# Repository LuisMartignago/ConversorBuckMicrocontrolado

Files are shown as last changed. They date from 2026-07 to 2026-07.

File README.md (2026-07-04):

# Conversor Buck Microcontrolado

Projeto de um conversor CC-CC abaixador (Buck Converter) com controle digital implementado em um microcontrolador **CH32V003**, desenvolvido com foco em aplicações de eletrônica de potência, sistemas embarcados e controle digital.

O projeto contempla o desenvolvimento completo do hardware e do firmware, incluindo o dimensionamento da etapa de potência, condicionamento dos sinais analógicos, controle por PWM, algoritmo de controle PI, proteção contra sobrecorrente e interface de comunicação serial.

---

## Principais características

* Conversor Buck microcontrolado.
* Controle digital de tensão utilizando controlador **PI**.
* Geração de PWM por hardware utilizando o temporizador **TIM1**.
* Aquisição de tensão e corrente através do ADC.
* Conversão automática utilizando **ADC + DMA**.
* Comunicação serial UART para monitoramento e configuração.
* Limitação de corrente por software.
* Controle de rampa (*Rate Limiter*) para partida suave e alterações da referência.
* Proteção contra *Integral Windup*.
* Firmware desenvolvido em linguagem C.
* Hardware desenvolvido no KiCad.

---

## Hardware

O conversor é composto pelos seguintes blocos principais:

* Microcontrolador **CH32V003**;
* Conversor Buck de potência;
* Driver para acionamento do MOSFET;
* Fonte auxiliar isolada para alimentação do gate driver;
* Reguladores de tensão para alimentação dos circuitos de controle;
* Divisor resistivo para medição da tensão;
* Resistor shunt para medição da corrente;
* Amplificador operacional interno do CH32V003 para condicionamento do sinal de corrente.

---

## Estratégia de controle

O controle da tensão de saída é realizado por um controlador **Proporcional–Integral (PI)**.

A implementação inclui:

* cálculo periódico do erro;
* atualização do termo integral;
* limitação do integrador (*Anti-Windup*);
* saturação da saída do controlador;
* atualização do ciclo de trabalho do PWM.

Para reduzir transitórios durante alterações da referência, foi implementado um algoritmo de **Rate Limiter**, permitindo variações graduais da tensão de saída.

Como mecanismo adicional de proteção, quando a corrente ultrapassa o limite configurado, a referência de tensão é reduzida gradualmente e o integrador do controlador é parcialmente descarregado, proporcionando recuperação rápida após a remoção da condição de sobrecorrente.

---

## Comunicação Serial

O firmware disponibiliza uma interface UART para:

* monitoramento da tensão;
* monitoramento da corrente;
* ajuste de parâmetros;
* depuração do sistema.

A transmissão utiliza **DMA**, reduzindo significativamente a utilização da CPU.

---

## Estrutura do repositório

```text
.
├── Firmware/
├── Hardware/
│   ├── Esquemáticos
│   ├── PCB
│   └── Bibliotecas
├── Documentação/
├── Imagens/
└── README.md
```

---

## Ferramentas utilizadas

* KiCad
* GCC para RISC-V
* WCH MounRiver Studio
* Git
* GitHub

---

## Aplicações

Este projeto pode ser utilizado como base para:

* estudos de Eletrônica de Potência;
* Sistemas Embarcados;
* Controle Digital;
* Fontes chaveadas;
* Conversores CC-CC;
* projetos acadêmicos;
* trabalhos de conclusão de curso.

---

## Licença

Este projeto está disponibilizado para fins acadêmicos e de pesquisa.

---

Caso este projeto seja utilizado em trabalhos acadêmicos, solicita-se a devida citação do repositório.

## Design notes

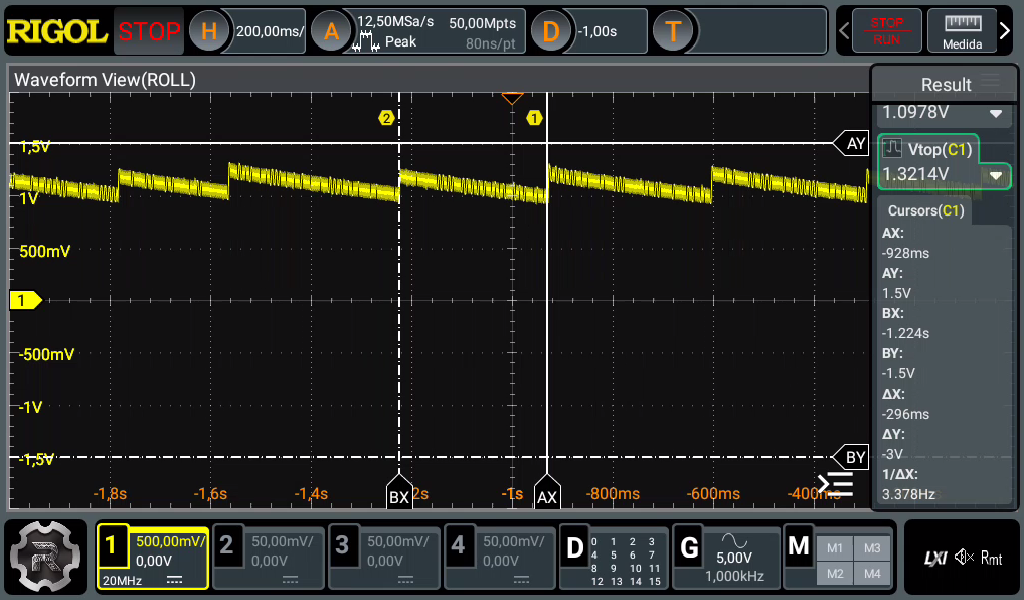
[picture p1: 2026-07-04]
FotosSaida/DMAuart.png

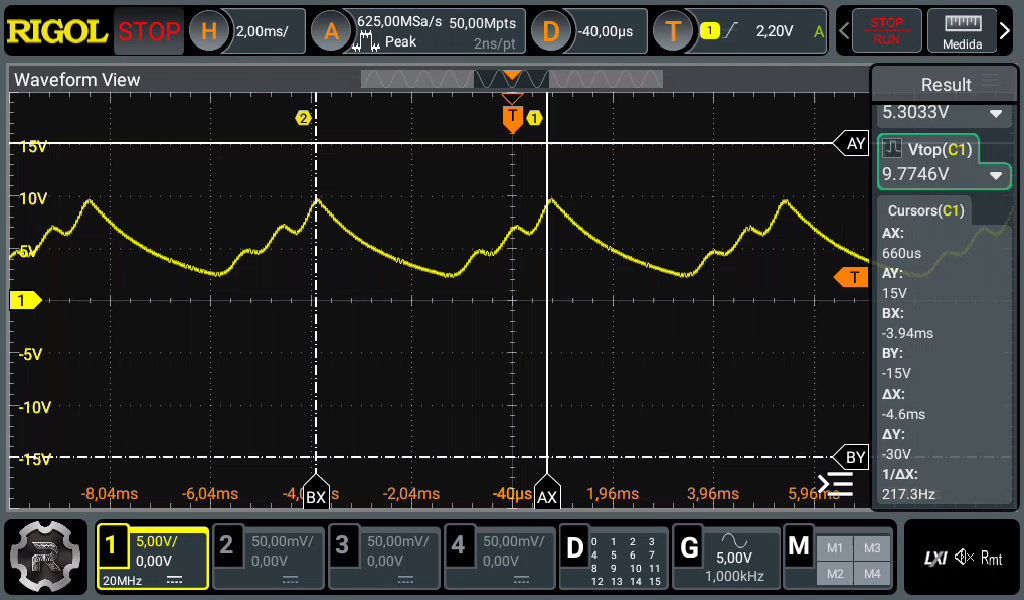
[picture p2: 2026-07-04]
FotosSaida/LimiteCorente.png

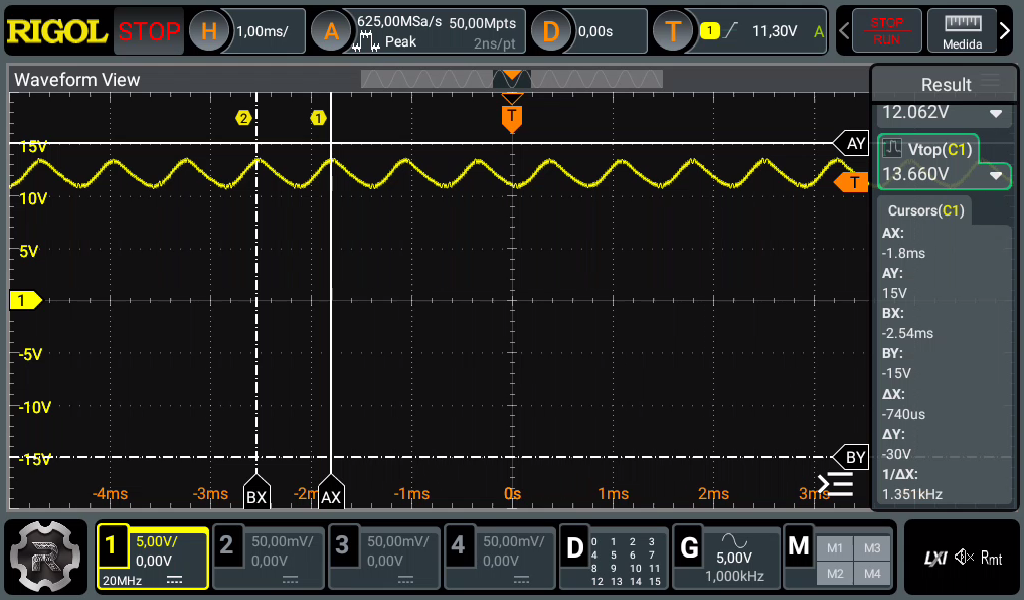
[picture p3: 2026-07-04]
FotosSaida/ProblemaSprintf.png

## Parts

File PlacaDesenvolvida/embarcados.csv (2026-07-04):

Id | Designador | Footprint | Quantidade | Designação | Fornecedor e referência
1 | C1, C2, C3 | CP_Elec_10x10 | 3 | 220uF
2 | C4, C5, C6 | C_1210_3225Metric_Pad1.33x2.70mm_HandSolder | 3 | 10uF
3 | C7, C8, C9, C10, C12, C13, C16, C18 | C_0603_1608Metric_Pad1.08x0.95mm_HandSolder | 8 | 0u1
4 | C11, C14, C15 | CP_Elec_4x3.9 | 3 | 10u
5 | C17 | C_0603_1608Metric_Pad1.08x0.95mm_HandSolder | 1 | 12p
6 | D1 | D_A-405_P7.62mm_Horizontal | 1 | D_Zener
7 | D2 | D_A-405_P7.62mm_Horizontal | 1 | ZMM15V
8 | D3, D4 | D_A-405_P7.62mm_Horizontal | 2 | 1N4148
9 | J1, J2 | TerminalBlock_MaiXu_MX126-5.0-02P_1x02_P5.00mm | 2 | Screw_Terminal_01x02
10 | J3 | PinHeader_1x03_P2.54mm_Vertical | 1 | Conn_01x03_Pin
11 | J4 | PinHeader_1x02_P2.54mm_Vertical | 1 | Conn_01x03_Pin
12 | L1 | IndutorEmbarcados | 1 | 470u
13 | PS1 | B1212s | 1 | B1212S
14 | Q1 | TDSON-8-1 | 1 | BSC190N15NS3G(TOKMAS)
15 | Q2 | SOT-323_SC-70 | 1 | PNP
16 | Q3 | TO-126-3_Vertical | 1 | BD139
17 | R2 | R_0603_1608Metric_Pad0.98x0.95mm_HandSolder | 1 | 10kΩ
18 | R4, R5 | R_1210_3225Metric_Pad1.30x2.65mm_HandSolder | 2 | 10Ω
19 | R6 | R_1210_3225Metric_Pad1.30x2.65mm_HandSolder | 1 | 220R
20 | R7 | R_0603_1608Metric_Pad0.98x0.95mm_HandSolder | 1 | 4k7
21 | R8, R9 | R_1210_3225Metric_Pad1.30x2.65mm_HandSolder | 2 | 0R1
22 | R10, R13 | R_Axial_DIN0207_L6.3mm_D2.5mm_P7.62mm_Horizontal | 2 | 10k
23 | R11, R12 | R_Axial_DIN0207_L6.3mm_D2.5mm_P7.62mm_Horizontal | 2 | 20k
24 | R14 | R_0603_1608Metric_Pad0.98x0.95mm_HandSolder | 1 | 15k
25 | R15 | R_0603_1608Metric_Pad0.98x0.95mm_HandSolder | 1 | 330R
26 | TP1 | TestPoint_Bridge_Pitch2.54mm_Drill0.7mm | 1 | GATE
27 | TP2 | TestPoint_Bridge_Pitch2.54mm_Drill0.7mm | 1 | SOURCE
28 | TP3 | TestPoint_Bridge_Pitch2.54mm_Drill0.7mm | 1 | I_amp
29 | TP4 | TestPoint_Bridge_Pitch2.54mm_Drill0.7mm | 1 | VOUT
30 | U1 | TO-263-2 | 1 | MUR1620CT
31 | U2 | SSO-6_6.8x4.6mm_P1.27mm_Clearance8mm | 1 | FOD8342TR2
32 | U3 | TO-220-3_Vertical | 1 | LM7812_TO220
33 | U4 | TO-263-3_TabPin2 | 1 | LM1084-5.0
34 | U5 | TSSOP-20_4.4x6.5mm_P0.65mm | 1 | CH32V003FxPx

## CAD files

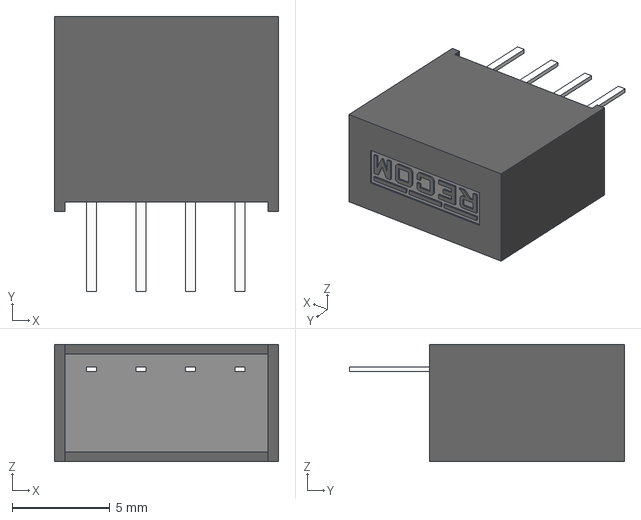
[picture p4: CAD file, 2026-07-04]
PlacaDesenvolvida/RO-1212S-HP--3DModel-STEP-1.STEP
11.5 x 14.1 x 6.00 mm

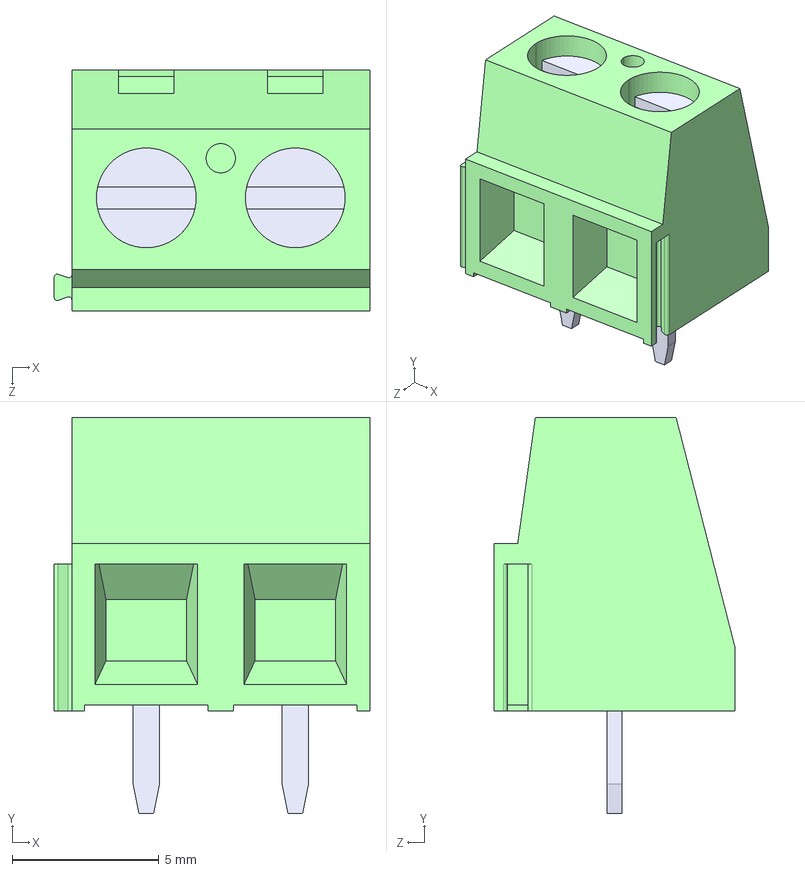
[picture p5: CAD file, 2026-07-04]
PlacaDesenvolvida/282837-2--3DModel-STEP-269445.STEP
10.8 x 13.5 x 8.20 mm

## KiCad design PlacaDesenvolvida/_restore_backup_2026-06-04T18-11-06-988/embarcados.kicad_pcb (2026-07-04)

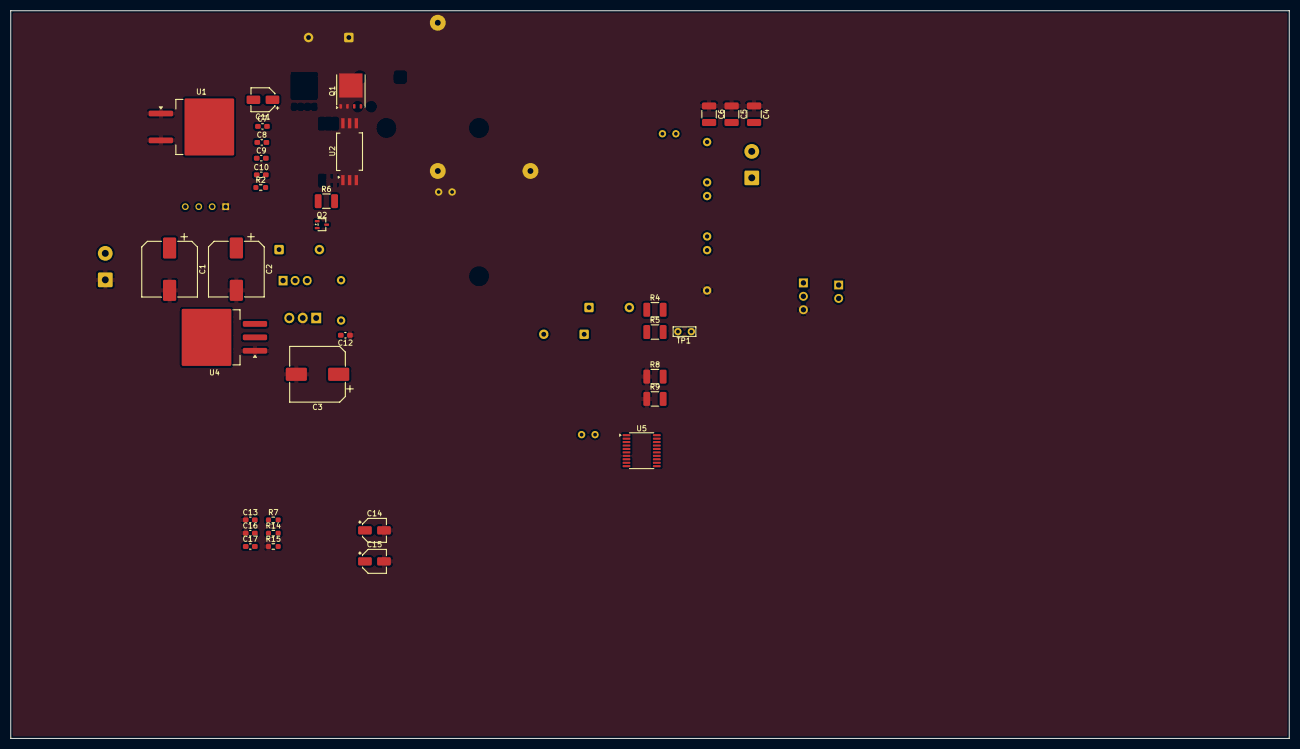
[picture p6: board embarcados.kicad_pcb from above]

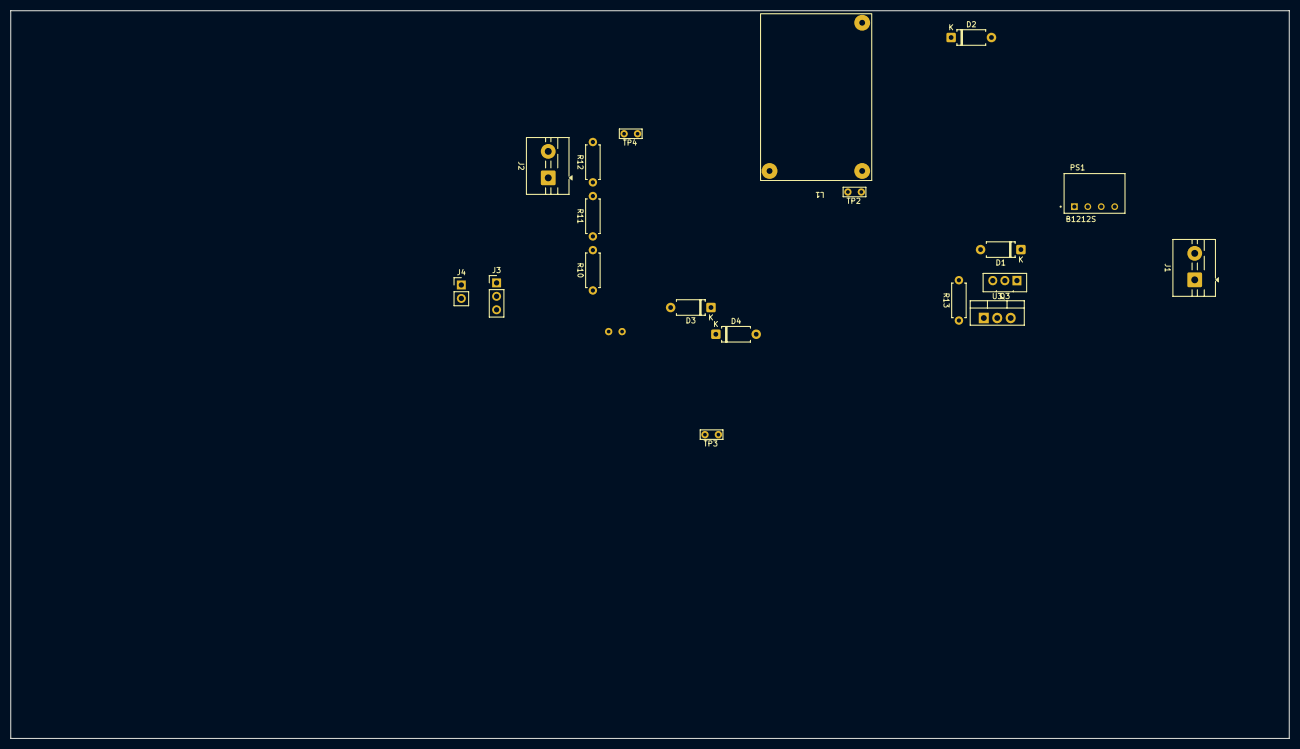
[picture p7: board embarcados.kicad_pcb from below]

Board: 2 copper layers, 241.5 x 137.5 mm, 52 parts (19 on the bottom side), 24 nets, no tracks yet.

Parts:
C1, C2, C3: 220uF; CP_Elec_10x10
C4, C5, C6: 10uF; C_1210_3225Metric_Pad1.33x2.70mm_HandSolder
C7, C8, C9, C10, C12, C13, C16: 0u1; C_0603_1608Metric_Pad1.08x0.95mm_HandSolder
C11, C14, C15: 10u; CP_Elec_4x3.9
C17: 12p; C_0603_1608Metric_Pad1.08x0.95mm_HandSolder
D1: D_Zener; D_A-405_P7.62mm_Horizontal
D2: ZMM15V; D_A-405_P7.62mm_Horizontal
D3, D4: 1N4148; D_A-405_P7.62mm_Horizontal
J1, J2: Screw_Terminal_01x02; TerminalBlock_MaiXu_MX126-5.0-02P_1x02_P5.00mm
J3: Conn_01x03_Pin; PinHeader_1x03_P2.54mm_Vertical
J4: Conn_01x03_Pin; PinHeader_1x02_P2.54mm_Vertical
L1: 470u; IndutorEmbarcados
PS1: B1212S; B1212s
Q1: BSC190N15NS3G(TOKMAS); TDSON-8-1
Q2: PNP; SOT-323_SC-70
Q3: BD139; TO-126-3_Vertical
R2: 10kΩ; R_0603_1608Metric_Pad0.98x0.95mm_HandSolder
R4, R5: 10Ω; R_1210_3225Metric_Pad1.30x2.65mm_HandSolder
R6: 220R; R_1210_3225Metric_Pad1.30x2.65mm_HandSolder
R7: 4k7; R_0603_1608Metric_Pad0.98x0.95mm_HandSolder
R8, R9: 0R1; R_1210_3225Metric_Pad1.30x2.65mm_HandSolder
R10, R13: 10k; R_Axial_DIN0207_L6.3mm_D2.5mm_P7.62mm_Horizontal
R11, R12: 20k; R_Axial_DIN0207_L6.3mm_D2.5mm_P7.62mm_Horizontal
R14: 15k; R_0603_1608Metric_Pad0.98x0.95mm_HandSolder
R15: 330R; R_0603_1608Metric_Pad0.98x0.95mm_HandSolder
TP1: GATE; TestPoint_Bridge_Pitch2.54mm_Drill0.7mm
TP2: SOURCE; TestPoint_Bridge_Pitch2.54mm_Drill0.7mm
TP3: I_amp; TestPoint_Bridge_Pitch2.54mm_Drill0.7mm
TP4: VOUT; TestPoint_Bridge_Pitch2.54mm_Drill0.7mm
U1: MUR1620CT; TO-263-2
U2: FOD8342TR2; SSO-6_6.8x4.6mm_P1.27mm_Clearance8mm
U3: LM7812_TO220; TO-220-3_Vertical
U4: LM1084-5.0; TO-263-3_TabPin2
U5: CH32V003FxPx; TSSOP-20_4.4x6.5mm_P0.65mm

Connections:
+5V: C15.1, C16.2, J3.1, Q2.3 (E), U4.2 (VO), U5.9 (VDD)
+12V: C13.2, C14.1, PS1.2 (+VIN), U3.3 (VO), U4.3 (VI)
+12Visolated: C7.2, C8.2, C9.2, C10.2, C11.1, PS1.4 (+VOUT), U2.6 (VDD)
+24V: C1.1, C2.1, D1.1 (K), J1.2, Q1.5 (D), Q3.2 (C)
GND: C1.2, C2.2, C3.2, C4.1, C5.1, C6.1, C12.1, C13.1, C14.2, C15.2, C16.1, J1.1, J3.3, PS1.1 (-VIN), R8.1, R9.1, R10.1, R15.1, U1.1 (A), U1.3 (A), U2.2 (NC), U2.3 (CATHODE), U3.2 (GND), U4.1 (GND), U5.7 (VSS)
I_sense: J2.1, R8.2, R9.2, U5.4 (PD7)
unnamed: D1.2 (A), Q3.3 (B), R13.2
unnamed: D2.1 (K), Q1.4 (G), R2.2, R4.2, R5.2, TP1.1 (1_1)
unnamed: D3.2 (A), D4.1 (C), U2.5 (VO)
unnamed: D3.1 (C), R4.1
unnamed: D4.2 (A), R5.1
unnamed: Q2.2 (B), R7.2
unnamed: Q2.1 (C), R6.1
unnamed: C3.1, C12.2, Q3.1 (E), R13.1, U3.1 (VI)
unnamed: R11.2, R12.1
unnamed: R6.2, U2.1 (ANODE)
unnamed: C17.2, R14.2, R15.2, U5.8 (PD0)
unnamed: C17.1, R14.1, TP3.1 (1_1), U5.1 (PD4)
PD1: J3.2, U5.18 (PD1)
RX: J4.2, U5.3 (PD6)
TX: J4.1, U5.2 (PD5)
VSS: C7.1, C8.1, C9.1, C10.1, C11.2, D2.2 (A), L1.1, PS1.3 (-VOUT), Q1.1 (S), Q1.2 (S), Q1.3 (S), R2.1, TP2.1 (1_1), U1.2 (C), U2.4 (VSS)
Vout+: C4.2, C5.2, C6.2, J2.2, L1.2, R12.2, TP4.1 (1_1)
Vsense: R10.2, R11.1, U5.19 (PD2)

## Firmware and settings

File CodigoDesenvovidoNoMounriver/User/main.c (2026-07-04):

#include "debug.h"


// ======== Variaveis Globais ======== //

// -------- ADC --------
#define V_pin GPIO_Pin_2
#define I_pin GPIO_Pin_4
#define V_ADC ADC_Channel_3
#define I_ADC ADC_Channel_7

#define V_sample ADC_SampleTime_30Cycles
#define I_sample ADC_SampleTime_30Cycles
volatile u16 adc_buf[2];
volatile u16 ADC_COMPLETE;
volatile u16 V_lido;
volatile u16 I_lido;

// -------- USART --------
volatile uint32_t V_recebido = 0;
volatile uint32_t I_recebido = 0;
#define TxSize (size (exemplo_TX))
#define RxSize (size (exemplo_RX))
#define size(a) (sizeof (a) / sizeof (*(a)))
#define exemplo_TX "V:1023,I:1023\r\n"
#define exemplo_RX "V:1023,I:1023\r\n"

volatile char TxBuffer[TxSize] = {0};
volatile char RxBuffer[RxSize] = {0};
volatile u32 Tx_pronto = 0;
volatile u32 Rx_pronto = 0;

//--------- Variaveis Globais -------
u16 PWM = 0;
#define TIM1_PSC 1 - 1  // Timer do PWM
#define TIM1_ARR 480 - 1

//-------- variaveis e defines do controle ------
#define PWM_MAX     480 - 60
#define PWM_MIN     8

#define KP          6   // 2
#define KI          4   // 4
#define SHIFT       4   // 4

#define V_FPB_STEP    10
#define I_FPB_STEP    40

#define INT_MAX     3000   // 824//927 //800 //340
#define INT_MIN     -3000  // 824//927 //800 //340

u32 V_ref = 0;
u32 I_ref = 0;


// ======== Prototipos ======== //

// -------- Inicializar sistema --------
void Custom_Option_Byte_CFG (void);
void Custom_TIM1_CFG (void);
void Custom_OPA1_CFG (void);
void Custom_ADC_CFG (u16 CCR);
void Custom_PWM_CFG (void);
void Custom_USARTx_CFG (void);
void EXTI0_INT_CFG (void);

// -------- Interrupt --------
void USART1_IRQHandler (void) __attribute__ ((interrupt));
void DMA1_Channel1_IRQHandler (void) __attribute__ ((interrupt (("WCH-Interrupt-fast"))));

// -------- Funcoes do usuario --------
void ControleBuck (void);
void Verifica_RX (void);

// ======== Main ======== //

int main (void) {

    RCC_PLLCmd (ENABLE);
    RCC_SYSCLKConfig (RCC_SYSCLKSource_PLLCLK);
    NVIC_PriorityGroupConfig (NVIC_PriorityGroup_1);
    // SystemCoreClockUpdate();
    // SystemInit();
    Delay_Init();

    Custom_Option_Byte_CFG();
    Custom_TIM1_CFG();
    Custom_OPA1_CFG();
    Custom_ADC_CFG (0);
    Custom_PWM_CFG();
    Custom_USARTx_CFG();

    USART_DMACmd (USART1, USART_DMAReq_Tx, ENABLE);
    USART_DMACmd (USART1, USART_DMAReq_Rx, ENABLE);

    while (1) {
        if (ADC_COMPLETE)
            ControleBuck();
        if (Rx_pronto)
            Verifica_RX();
        sprintf ((char *)TxBuffer, "V:%04d,I:%04d\r\n", V_lido, I_lido);
    }
}

// ======== Funcoes ======== //

void ControleBuck (void) {
    volatile static int32_t integral = 0;
    volatile static int32_t erro = 0;
    volatile static u32     PROTECAO_ATIVA = 0;
    volatile static u32     V_PID = 0;

    volatile int32_t saida = 0;

    /* ---------- Filtro passa baixa e protecao de corrente ---------- */
    PROTECAO_ATIVA = (I_lido > I_ref);
    
    if (PROTECAO_ATIVA) {
        integral -= integral >> 3; // Subtrai integral/8

        if(V_PID > I_FPB_STEP) V_PID -= I_FPB_STEP;
        else V_PID = 0;
    }
    else {
        if (V_PID < V_ref) {
            V_PID += V_FPB_STEP;
            if (V_PID > V_ref) V_PID = V_ref;
        }
        else if (V_PID > V_ref) {
            V_PID -= V_FPB_STEP;
            if (V_PID < V_ref) V_PID = V_ref;
        }
    }

    /* ---------- Controle de tensao ---------- */
    erro = V_PID - V_lido;

    saida = ((KP * erro) + (KI * integral)) >> SHIFT;

    /* ---------- Saturacao e anti windup ---------- */
    if(saida < PWM_MIN) saida = 0;
    else if (saida > PWM_MAX) saida = TIM1_ARR+1;
    else if (!PROTECAO_ATIVA) {
        integral += erro;

        if (integral > INT_MAX)         integral = INT_MAX;
        else if (integral < INT_MIN)    integral = INT_MIN;
    }

    TIM_SetCompare3 (TIM1, (u16)saida);
    ADC_COMPLETE = RESET;
}

void Verifica_RX (void) {
    uint8_t len = RxSize - DMA_GetCurrDataCounter (DMA1_Channel5);  // Quantos bytes chegaram

    /* Coloca terminador */
    if (len >= RxSize) {
        len = RxSize - 1;
        RxBuffer[len] = '\0';
    }

    /* Faz o parse da mensagem */
    if (sscanf ((char *)RxBuffer, "V:%04u,I:%04u", &V_recebido, &I_recebido) == 2) {
        V_ref = V_recebido;
        I_ref = I_recebido;
    }

    /* Rearma DMA */
    DMA_SetCurrDataCounter (DMA1_Channel5, RxSize);
    DMA_Cmd (DMA1_Channel5, ENABLE);
    Rx_pronto = RESET;
}

// ======== Interrupt ======== //


void DMA1_Channel1_IRQHandler (void) {
    // ADC
    DMA_ClearITPendingBit (DMA1_IT_TC1);
    V_lido = adc_buf[0];
    I_lido = adc_buf[1];
    ADC_COMPLETE = SET;
}

void USART1_IRQHandler (void) {
    if (USART_GetITStatus (USART1, USART_IT_IDLE)) {
        DMA_Cmd (DMA1_Channel5, DISABLE);  // Para DMA
        Rx_pronto = SET;

        /* Limpa a flag IDLE */
        USART1->STATR;
        USART1->DATAR;
    }
}

// ======== Inicializar sistema ======== //

void Custom_Option_Byte_CFG (void) {
    // Desabilita pino do reset
    FLASH_Unlock();
    FLASH_EraseOptionBytes();
    FLASH_UserOptionByteConfig (OB_IWDG_SW, OB_STDBY_NoRST, OB_RST_NoEN, OB_PowerON_Start_Mode_BOOT);
    FLASH_Lock();
}

void Custom_TIM1_CFG (void) {
    TIM_TimeBaseInitTypeDef TIM1_TimeBaseInitStructure = {0};
    RCC_APB2PeriphClockCmd (RCC_APB2Periph_TIM1, ENABLE);

    TIM1_TimeBaseInitStructure.TIM_Prescaler = TIM1_PSC;
    TIM1_TimeBaseInitStructure.TIM_Period = TIM1_ARR;
    TIM1_TimeBaseInitStructure.TIM_ClockDivision = TIM_CKD_DIV1;
    TIM1_TimeBaseInitStructure.TIM_CounterMode = TIM_CounterMode_Up;
    TIM_TimeBaseInit (TIM1, &TIM1_TimeBaseInitStructure);

    TIM_Cmd (TIM1, ENABLE);
}

void Custom_OPA1_CFG (void) {
    GPIO_InitTypeDef GPIO_InitStructure = {0};
    OPA_InitTypeDef OPA_InitStructure = {0};
    RCC_APB2PeriphClockCmd (RCC_APB2Periph_GPIOD, ENABLE);

    GPIO_InitStructure.GPIO_Pin = GPIO_Pin_7;
    GPIO_InitStructure.GPIO_Mode = GPIO_Mode_IN_FLOATING;
    GPIO_Init (GPIOD, &GPIO_InitStructure);
    GPIO_PinLockConfig (GPIOD, GPIO_Pin_7);

    GPIO_InitStructure.GPIO_Pin = GPIO_Pin_0;
    GPIO_InitStructure.GPIO_Mode = GPIO_Mode_IN_FLOATING;
    GPIO_Init (GPIOD, &GPIO_InitStructure);

    OPA_InitStructure.PSEL = CHP1;
    OPA_InitStructure.NSEL = CHN1;
    OPA_Init (&OPA_InitStructure);

    OPA_Cmd (ENABLE);
}

void Custom_ADC_CFG (uint16_t CCR) {
    // -------- Trigger CFG --------

    TIM_OCInitTypeDef TIM_OCInitStructure = {0};

    TIM_OCInitStructure.TIM_OCMode = TIM_OCMode_Timing;
    TIM_OCInitStructure.TIM_OutputState = TIM_OutputState_Disable;
    TIM_OCInitStructure.TIM_Pulse = CCR;
    TIM_OCInitStructure.TIM_OCPolarity = TIM_OCPolarity_High;
    TIM_OC2Init (TIM1, &TIM_OCInitStructure);  // CC2 confgiurado como referencia
    TIM_OC2PreloadConfig (TIM1, TIM_OCPreload_Enable);


    // -------- DMA CFG --------

    DMA_InitTypeDef DMA_InitStructure = {0};
    RCC_AHBPeriphClockCmd (RCC_AHBPeriph_DMA1, ENABLE);

    DMA_DeInit (DMA1_Channel1);
    DMA_InitStructure.DMA_PeripheralBaseAddr = (u32)&ADC1->RDATAR;
    DMA_InitStructure.DMA_MemoryBaseAddr = (u32)adc_buf;  // 2 valores (scan length = 2)
    DMA_InitStructure.DMA_BufferSize = size (adc_buf);
    DMA_InitStructure.DMA_DIR = DMA_DIR_PeripheralSRC;
    DMA_InitStructure.DMA_PeripheralInc = DMA_PeripheralInc_Disable;
    DMA_InitStructure.DMA_MemoryInc = DMA_MemoryInc_Enable;
    DMA_InitStructure.DMA_PeripheralDataSize = DMA_PeripheralDataSize_HalfWord;
    DMA_InitStructure.DMA_MemoryDataSize = DMA_MemoryDataSize_HalfWord;
    DMA_InitStructure.DMA_Mode = DMA_Mode_Circular;      // Cont??nuo
    DMA_InitStructure.DMA_Priority = DMA_Priority_High;  // A USART RX tem prioridade maior
    DMA_InitStructure.DMA_M2M = DMA_M2M_Disable;
    DMA_Init (DMA1_Channel1, &DMA_InitStructure);
    DMA_Cmd (DMA1_Channel1, ENABLE);

    // -------- Interrupt --------

    NVIC_InitTypeDef NVIC_InitStructure = {0};
    NVIC_InitStructure.NVIC_IRQChannel = DMA1_Channel1_IRQn;
    NVIC_InitStructure.NVIC_IRQChannelPreemptionPriority = 0;
    NVIC_InitStructure.NVIC_IRQChannelSubPriority = 1;
    NVIC_InitStructure.NVIC_IRQChannelCmd = ENABLE;
    NVIC_Init (&NVIC_InitStructure);
    DMA_ITConfig (DMA1_Channel1, DMA_IT_TC, ENABLE);

    // -------- ADC CFG --------

    GPIO_InitTypeDef GPIO_InitStructure = {0};
    ADC_InitTypeDef ADC_InitStructure = {0};

    RCC_APB2PeriphClockCmd (RCC_APB2Periph_GPIOD, ENABLE);
    RCC_APB2PeriphClockCmd (RCC_APB2Periph_ADC1, ENABLE);
    RCC_ADCCLKConfig (RCC_PCLK2_Div2);

    GPIO_InitStructure.GPIO_Pin = V_pin | I_pin;
    GPIO_InitStructure.GPIO_Mode = GPIO_Mode_AIN;
    GPIO_InitStructure.GPIO_Speed = GPIO_Speed_50MHz;
    GPIO_Init (GPIOD, &GPIO_InitStructure);

    ADC_DeInit (ADC1);
    ADC_InitStructure.ADC_Mode = ADC_Mode_Independent;
    ADC_InitStructure.ADC_ScanConvMode = ENABLE;                           // Le os dois canais em sequencia
    ADC_InitStructure.ADC_ContinuousConvMode = ENABLE;                     // DISABLE;
    ADC_InitStructure.ADC_ExternalTrigConv = ADC_ExternalTrigConv_T1_CC2;  // Trigger
    ADC_InitStructure.ADC_DataAlign = ADC_DataAlign_Right;
    ADC_InitStructure.ADC_NbrOfChannel = 2;
    ADC_Init (ADC1, &ADC_InitStructure);

    ADC_RegularChannelConfig (ADC1, V_ADC, 1, V_sample);
    ADC_RegularChannelConfig (ADC1, I_ADC, 2, I_sample);

    ADC_Calibration_Vol (ADC1, ADC_CALVOL_50PERCENT);
    ADC_DMACmd (ADC1, ENABLE);
    ADC_Cmd (ADC1, ENABLE);

    ADC_ResetCalibration (ADC1);
    while (ADC_GetResetCalibrationStatus (ADC1));
    ADC_StartCalibration (ADC1);
    while (ADC_GetCalibrationStatus (ADC1));

    ADC_Cmd (ADC1, ENABLE);
}

void Custom_PWM_CFG (void) {
    GPIO_InitTypeDef GPIO_InitStructure = {0};
    TIM_OCInitTypeDef TIM_OCInitStructure = {0};

    GPIO_PinRemapConfig (GPIO_PartialRemap1_TIM1, ENABLE);

    RCC_APB2PeriphClockCmd (RCC_APB2Periph_GPIOC, ENABLE);

    GPIO_InitStructure.GPIO_Pin = GPIO_Pin_0;
    GPIO_InitStructure.GPIO_Mode = GPIO_Mode_AF_PP;
    GPIO_InitStructure.GPIO_Speed = GPIO_Speed_50MHz;
    GPIO_Init (GPIOC, &GPIO_InitStructure);

    TIM_OCInitStructure.TIM_OCMode = TIM_OCMode_PWM1;
    TIM_OCInitStructure.TIM_OutputState = TIM_OutputState_Enable;
    TIM_OCInitStructure.TIM_Pulse = 0;
    TIM_OCInitStructure.TIM_OCPolarity = TIM_OCPolarity_Low;
    TIM_OC3Init (TIM1, &TIM_OCInitStructure);

    TIM_OC3PreloadConfig (TIM1, TIM_OCPreload_Enable);
    TIM_ARRPreloadConfig (TIM1, ENABLE);

    TIM_CtrlPWMOutputs (TIM1, ENABLE);
}

void Custom_USARTx_CFG (void) {
    RCC_AHBPeriphClockCmd (RCC_AHBPeriph_DMA1, ENABLE);

    // -------- DMA TX --------

    DMA_InitTypeDef DMA_TX_InitStructure = {0};
    DMA_DeInit (DMA1_Channel4);
    DMA_TX_InitStructure.DMA_PeripheralBaseAddr = (u32)(&USART1->DATAR);
    DMA_TX_InitStructure.DMA_MemoryBaseAddr = (u32)TxBuffer;
    DMA_TX_InitStructure.DMA_DIR = DMA_DIR_PeripheralDST;
    DMA_TX_InitStructure.DMA_BufferSize = TxSize;
    DMA_TX_InitStructure.DMA_PeripheralInc = DMA_PeripheralInc_Disable;
    DMA_TX_InitStructure.DMA_MemoryInc = DMA_MemoryInc_Enable;
    DMA_TX_InitStructure.DMA_PeripheralDataSize = DMA_PeripheralDataSize_Byte;
    DMA_TX_InitStructure.DMA_MemoryDataSize = DMA_MemoryDataSize_Byte;
    DMA_TX_InitStructure.DMA_Mode = DMA_Mode_Circular;     // Envia pra sempre e foda-se
    DMA_TX_InitStructure.DMA_Priority = DMA_Priority_Low;  // Prioridade mais baixa do projeto
    DMA_TX_InitStructure.DMA_M2M = DMA_M2M_Disable;
    DMA_Init (DMA1_Channel4, &DMA_TX_InitStructure);


    // -------- DMA RX --------

    DMA_InitTypeDef DMA_RX_InitStructure = {0};
    DMA_DeInit (DMA1_Channel5);
    DMA_RX_InitStructure.DMA_PeripheralBaseAddr = (u32)(&USART1->DATAR);
    DMA_RX_InitStructure.DMA_MemoryBaseAddr = (u32)RxBuffer;
    DMA_RX_InitStructure.DMA_DIR = DMA_DIR_PeripheralSRC;
    DMA_RX_InitStructure.DMA_BufferSize = RxSize;
    DMA_RX_InitStructure.DMA_PeripheralInc = DMA_PeripheralInc_Disable;
    DMA_RX_InitStructure.DMA_MemoryInc = DMA_MemoryInc_Enable;
    DMA_RX_InitStructure.DMA_PeripheralDataSize = DMA_PeripheralDataSize_Byte;
    DMA_RX_InitStructure.DMA_MemoryDataSize = DMA_MemoryDataSize_Byte;
    DMA_RX_InitStructure.DMA_Mode = DMA_Mode_Normal;            // Recebe uma vez
    DMA_RX_InitStructure.DMA_Priority = DMA_Priority_VeryHigh;  // Prioridade mais alta do projeto
    DMA_RX_InitStructure.DMA_M2M = DMA_M2M_Disable;
    DMA_Init (DMA1_Channel5, &DMA_RX_InitStructure);

    NVIC_InitTypeDef NVIC_RX_InitStructure = {0};
    NVIC_RX_InitStructure.NVIC_IRQChannel = DMA1_Channel5_IRQn;
    NVIC_RX_InitStructure.NVIC_IRQChannelCmd = ENABLE;
    NVIC_RX_InitStructure.NVIC_IRQChannelPreemptionPriority = 1;
    NVIC_RX_InitStructure.NVIC_IRQChannelSubPriority = ENABLE;
    NVIC_Init (&NVIC_RX_InitStructure);

    // -------- USART --------
    GPIO_InitTypeDef GPIO_InitStructure = {0};
    USART_InitTypeDef USART_InitStructure = {0};

    RCC_APB2PeriphClockCmd (RCC_APB2Periph_GPIOD | RCC_APB2Periph_USART1, ENABLE);

    /* USART1 TX-->D.5   RX-->D.6 */
    GPIO_InitStructure.GPIO_Pin = GPIO_Pin_5;
    GPIO_InitStructure.GPIO_Speed = GPIO_Speed_50MHz;
    GPIO_InitStructure.GPIO_Mode = GPIO_Mode_AF_PP;
    GPIO_Init (GPIOD, &GPIO_InitStructure);

    GPIO_InitStructure.GPIO_Pin = GPIO_Pin_6;
    GPIO_InitStructure.GPIO_Mode = GPIO_Mode_IPU;  // Pull UP para RX
    GPIO_Init (GPIOD, &GPIO_InitStructure);

    USART_InitStructure.USART_BaudRate = 115200;
    USART_InitStructure.USART_WordLength = USART_WordLength_8b;
    USART_InitStructure.USART_StopBits = USART_StopBits_1;
    USART_InitStructure.USART_Parity = USART_Parity_No;
    USART_InitStructure.USART_HardwareFlowControl = USART_HardwareFlowControl_None;
    USART_InitStructure.USART_Mode = USART_Mode_Tx | USART_Mode_Rx;
    USART_Init (USART1, &USART_InitStructure);

    NVIC_InitTypeDef NVIC_InitStructure = {0};
    NVIC_InitStructure.NVIC_IRQChannel = USART1_IRQn;
    NVIC_InitStructure.NVIC_IRQChannelPreemptionPriority = 1;
    NVIC_InitStructure.NVIC_IRQChannelSubPriority = 0;
    NVIC_InitStructure.NVIC_IRQChannelCmd = ENABLE;
    NVIC_Init (&NVIC_InitStructure);

    USART_ITConfig (USART1, USART_IT_IDLE, ENABLE);

    DMA_Cmd (DMA1_Channel4, ENABLE); /* USART1 Tx */
    DMA_Cmd (DMA1_Channel5, ENABLE); /* USART1 Rx */

    USART_Cmd (USART1, ENABLE);
}

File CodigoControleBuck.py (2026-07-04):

import tkinter as tk
from tkinter import ttk
import serial
import serial.tools.list_ports
import threading
import re
from collections import deque


ser = None

# Número de amostras para a média
N_MEDIA = 500

# Buffers circulares
buffer_v = deque(maxlen=N_MEDIA)
buffer_i = deque(maxlen=N_MEDIA)

#######################################################
# Conversões
#######################################################

def tensao_para_adc(v):

    valor = (v - 0.1174) / 0.0239

    valor = int(round(valor))

    valor = max(0, min(9999, valor))

    return valor



def corrente_para_adc(i):

    valor = ((i*1000) - 7.9) / 1.1651

    valor = int(round(valor))

    valor = max(0, min(9999, valor))

    return valor




def adc_para_tensao(adc):
    # Se o microcontrolador enviou 0, mostrar 0 V
    if adc == 0:
        return 0.0

    return adc * 0.0239 + 0.1174


def adc_para_corrente(adc):
    # Se o microcontrolador enviou 0, mostrar 0 A
    if adc == 0:
        return 0.0

    return (adc * 1.1651 + 7.9) / 1000



#######################################################
# UART
#######################################################

def conectar():

    global ser


    try:

        ser = serial.Serial(
                porta.get(),
                115200,
                timeout=0.1)

        status.config(text="Conectado")

        threading.Thread(
            target=receber,
            daemon=True
        ).start()


    except Exception as e:

        status.config(text=str(e))




def enviar():

    global ser

    if ser is None:
        return



    try:

        v = float(entry_v.get())
        i = float(entry_i.get())


        V = tensao_para_adc(v)
        I = corrente_para_adc(i)



        msg = f"V:{V:04d},I:{I:04d}\r\n"



        ser.write(msg.encode())


        enviado.config(
            text="TX: "+msg.strip()
        )


    except Exception as e:

        enviado.config(text=str(e))




def receber():

    global ser


    while True:

        try:

            linha = ser.readline().decode(errors='ignore')


            m = re.search(
                r'V:(\d+),I:(\d+)',
                linha
            )

            if m:


                Vadc = int(m.group(1))
                Iadc = int(m.group(2))


                Vreal = adc_para_tensao(Vadc)
                Ireal = adc_para_corrente(Iadc)

                # Adiciona ao buffer
                buffer_v.append(Vreal)
                buffer_i.append(Ireal)

                # Calcula as médias
                Vmedia = sum(buffer_v) / len(buffer_v)
                Imedia = sum(buffer_i) / len(buffer_i)

                # Exibe as médias
                recebido.config(
                    text=f"RX  V={Vmedia:.2f} V   "
                         f"I={Imedia:.3f} A"
                )
                



        except:
            pass




#######################################################
# Interface
#######################################################

janela = tk.Tk()

janela.title("Buck Terminal")
janela.geometry("420x250")



ttk.Label(janela,text="Porta COM").pack()


porta = ttk.Combobox(
            janela,
            values=[
                p.device
                for p in serial.tools.list_ports.comports()
            ]
)

porta.pack()




ttk.Button(
    janela,
    text="Conectar",
    command=conectar
).pack(pady=5)




status = ttk.Label(janela,text="Desconectado")
status.pack()



ttk.Label(janela,text="Tensão (V)")
ttk.Label(janela,text="Tensão (V)").pack()


entry_v = ttk.Entry(janela)
entry_v.insert(0,"5")
entry_v.pack()



ttk.Label(janela,text="Corrente (A)").pack()

entry_i = ttk.Entry(janela)
entry_i.insert(0,"1")
entry_i.pack()



ttk.Button(
    janela,
    text="Enviar",
    command=enviar
).pack(pady=10)



enviado = ttk.Label(janela,text="TX:")
enviado.pack()


recebido = ttk.Label(janela,text="RX:")
recebido.pack()



janela.mainloop()
